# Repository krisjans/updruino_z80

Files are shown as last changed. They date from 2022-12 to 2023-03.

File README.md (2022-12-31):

# updruino_z80
Use Updruino FPGA boarad (iCE40-UP5K-SG48) as bridge between ZX Spectrum and Raspberry Pi

# warning!
This project uses iCE40-UP5K-SG48 in "CRAM" mode.

By default Updruino ships in "flash mode".

You must re-solder two 0Ohm resistors from Horizontal "Flash" positions to vertical "CRAM" positions.

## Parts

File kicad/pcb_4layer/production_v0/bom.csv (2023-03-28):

Designator | Footprint | Quantity | Value | LCSC Part #
C1, C10, C16, C18, C19, C2, C20, C23, C24, C25, C27, C28, C3, C4, C5, C6, C8, C9 | C_0805_2012Metric | 18 | 0.1uF
C11, C12, C13, C14, C15, C17, C29 | C_0805_2012Metric | 7 | 4.7uF
D1 | D_SOD-123 | 1 | B5819W SL | C8598
R1, R10, R11, R12, R13, R14, R15, R16, R17, R18, R19, R2, R9 | R_1206_3216Metric | 13 | 10K
R3, R4, R5, R6 | R_0805_2012Metric | 4 | 510
R7, R8 | R_0805_2012Metric | 2 | 240
U1, U3, U5, U6 | TSSOP-24_L7.8-W4.4-P0.65-LS6.4-BL | 4 | SN74LVCC4245APWR | C7035
U2 | SOP-28_L18.2-W8.5-P1.27-LS12.1-BL | 1 | LY62256SL-70LLI | C261868
U7, U8 | SOIC-14_L8.7-W3.9-P1.27-LS6.0-BL | 2 | 74HC125D | C5598

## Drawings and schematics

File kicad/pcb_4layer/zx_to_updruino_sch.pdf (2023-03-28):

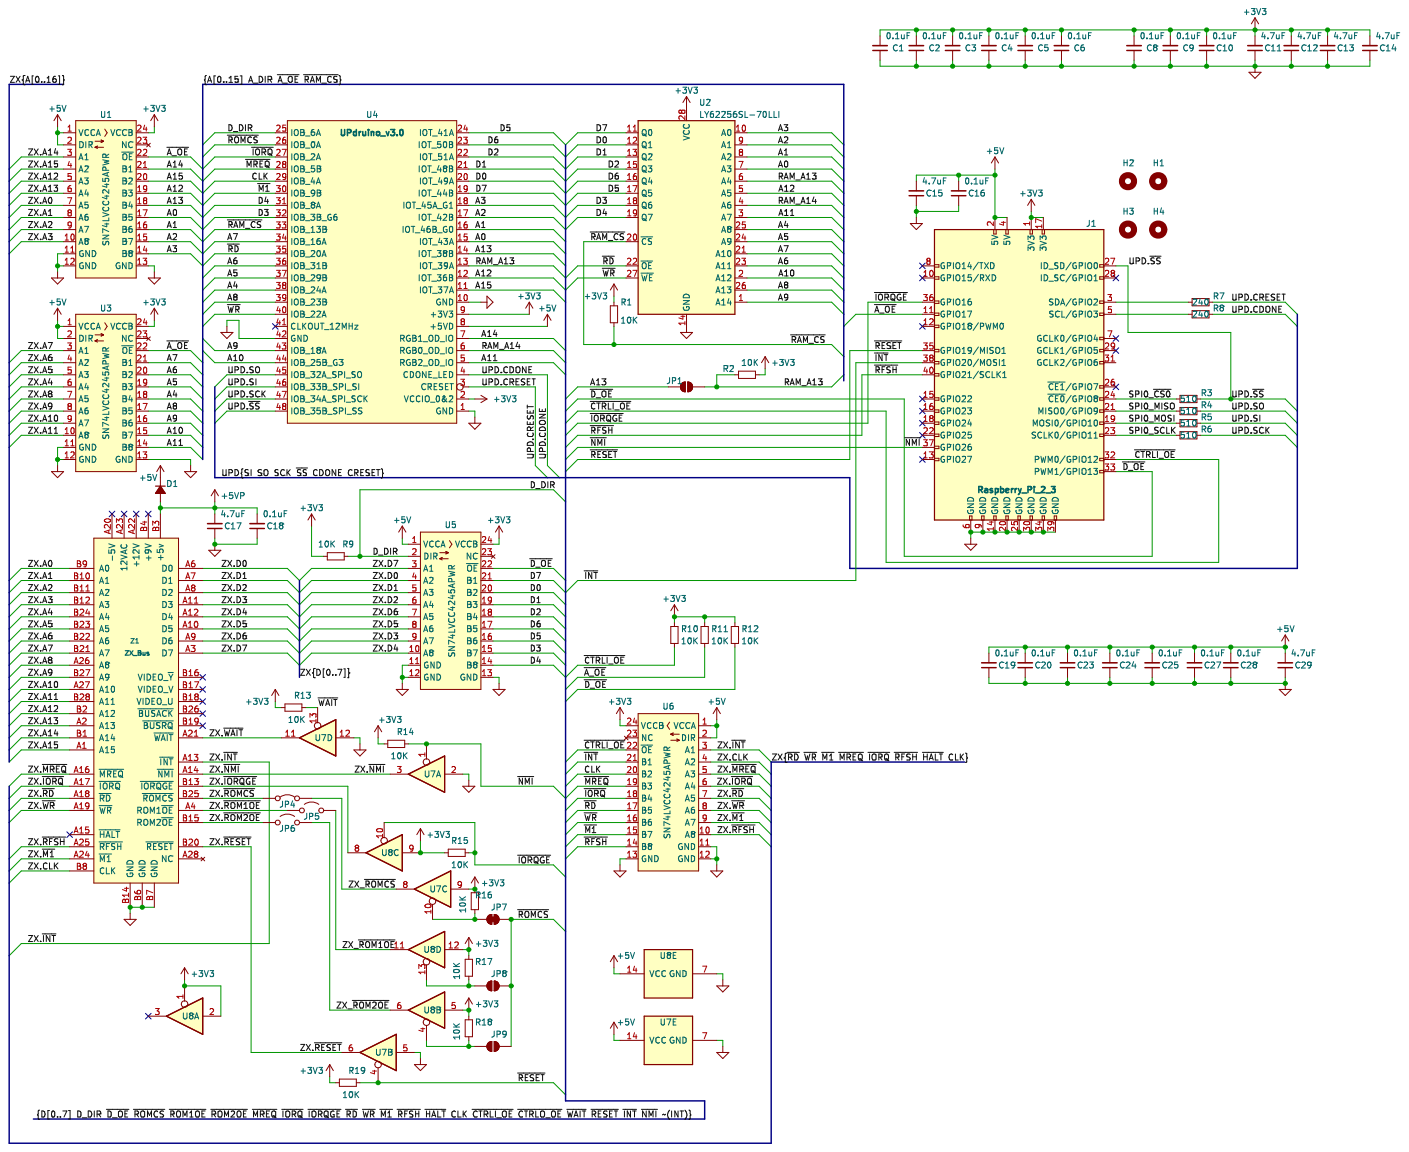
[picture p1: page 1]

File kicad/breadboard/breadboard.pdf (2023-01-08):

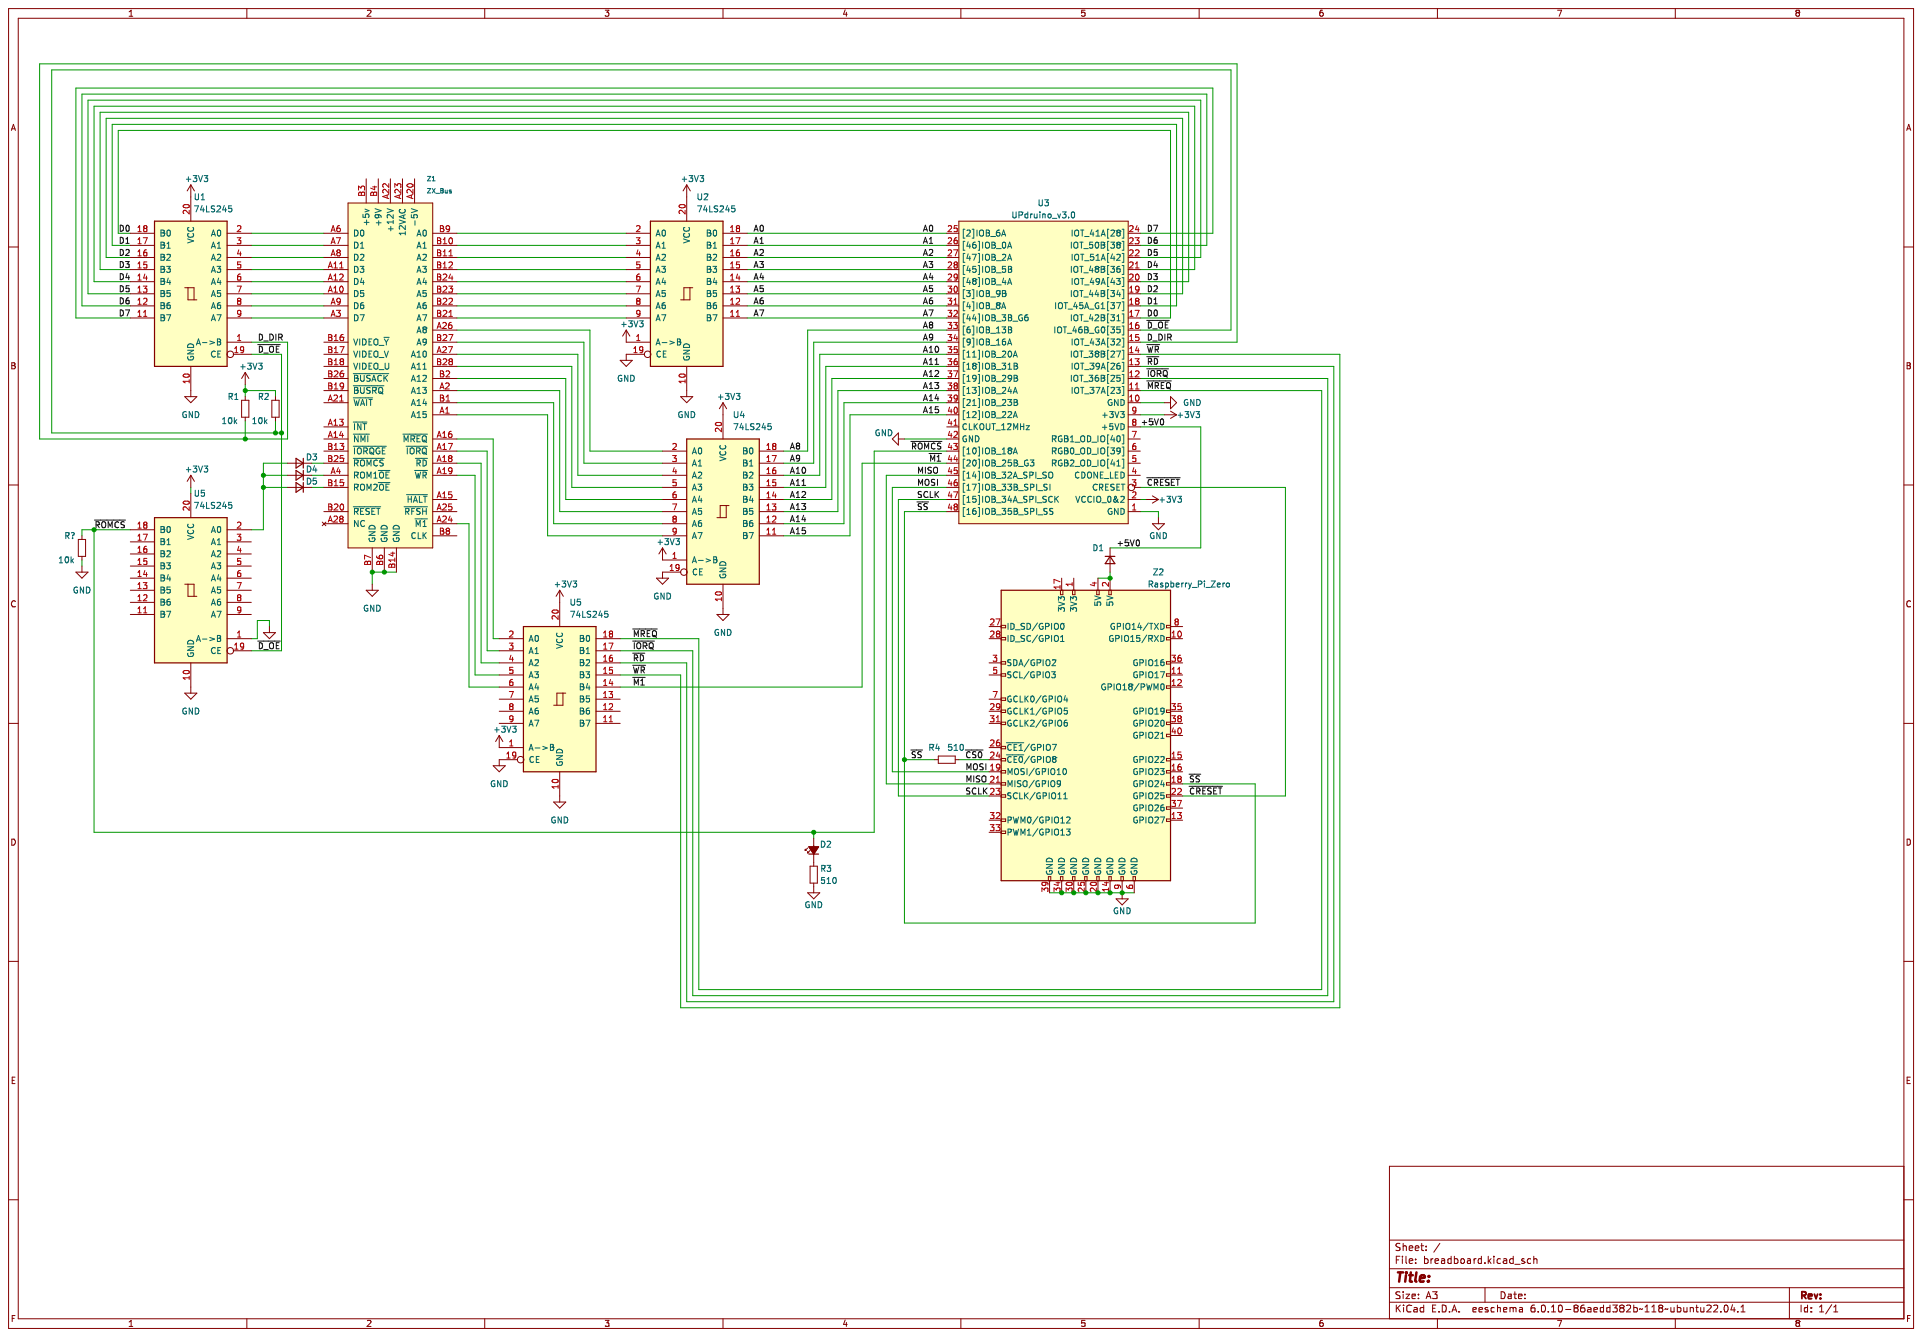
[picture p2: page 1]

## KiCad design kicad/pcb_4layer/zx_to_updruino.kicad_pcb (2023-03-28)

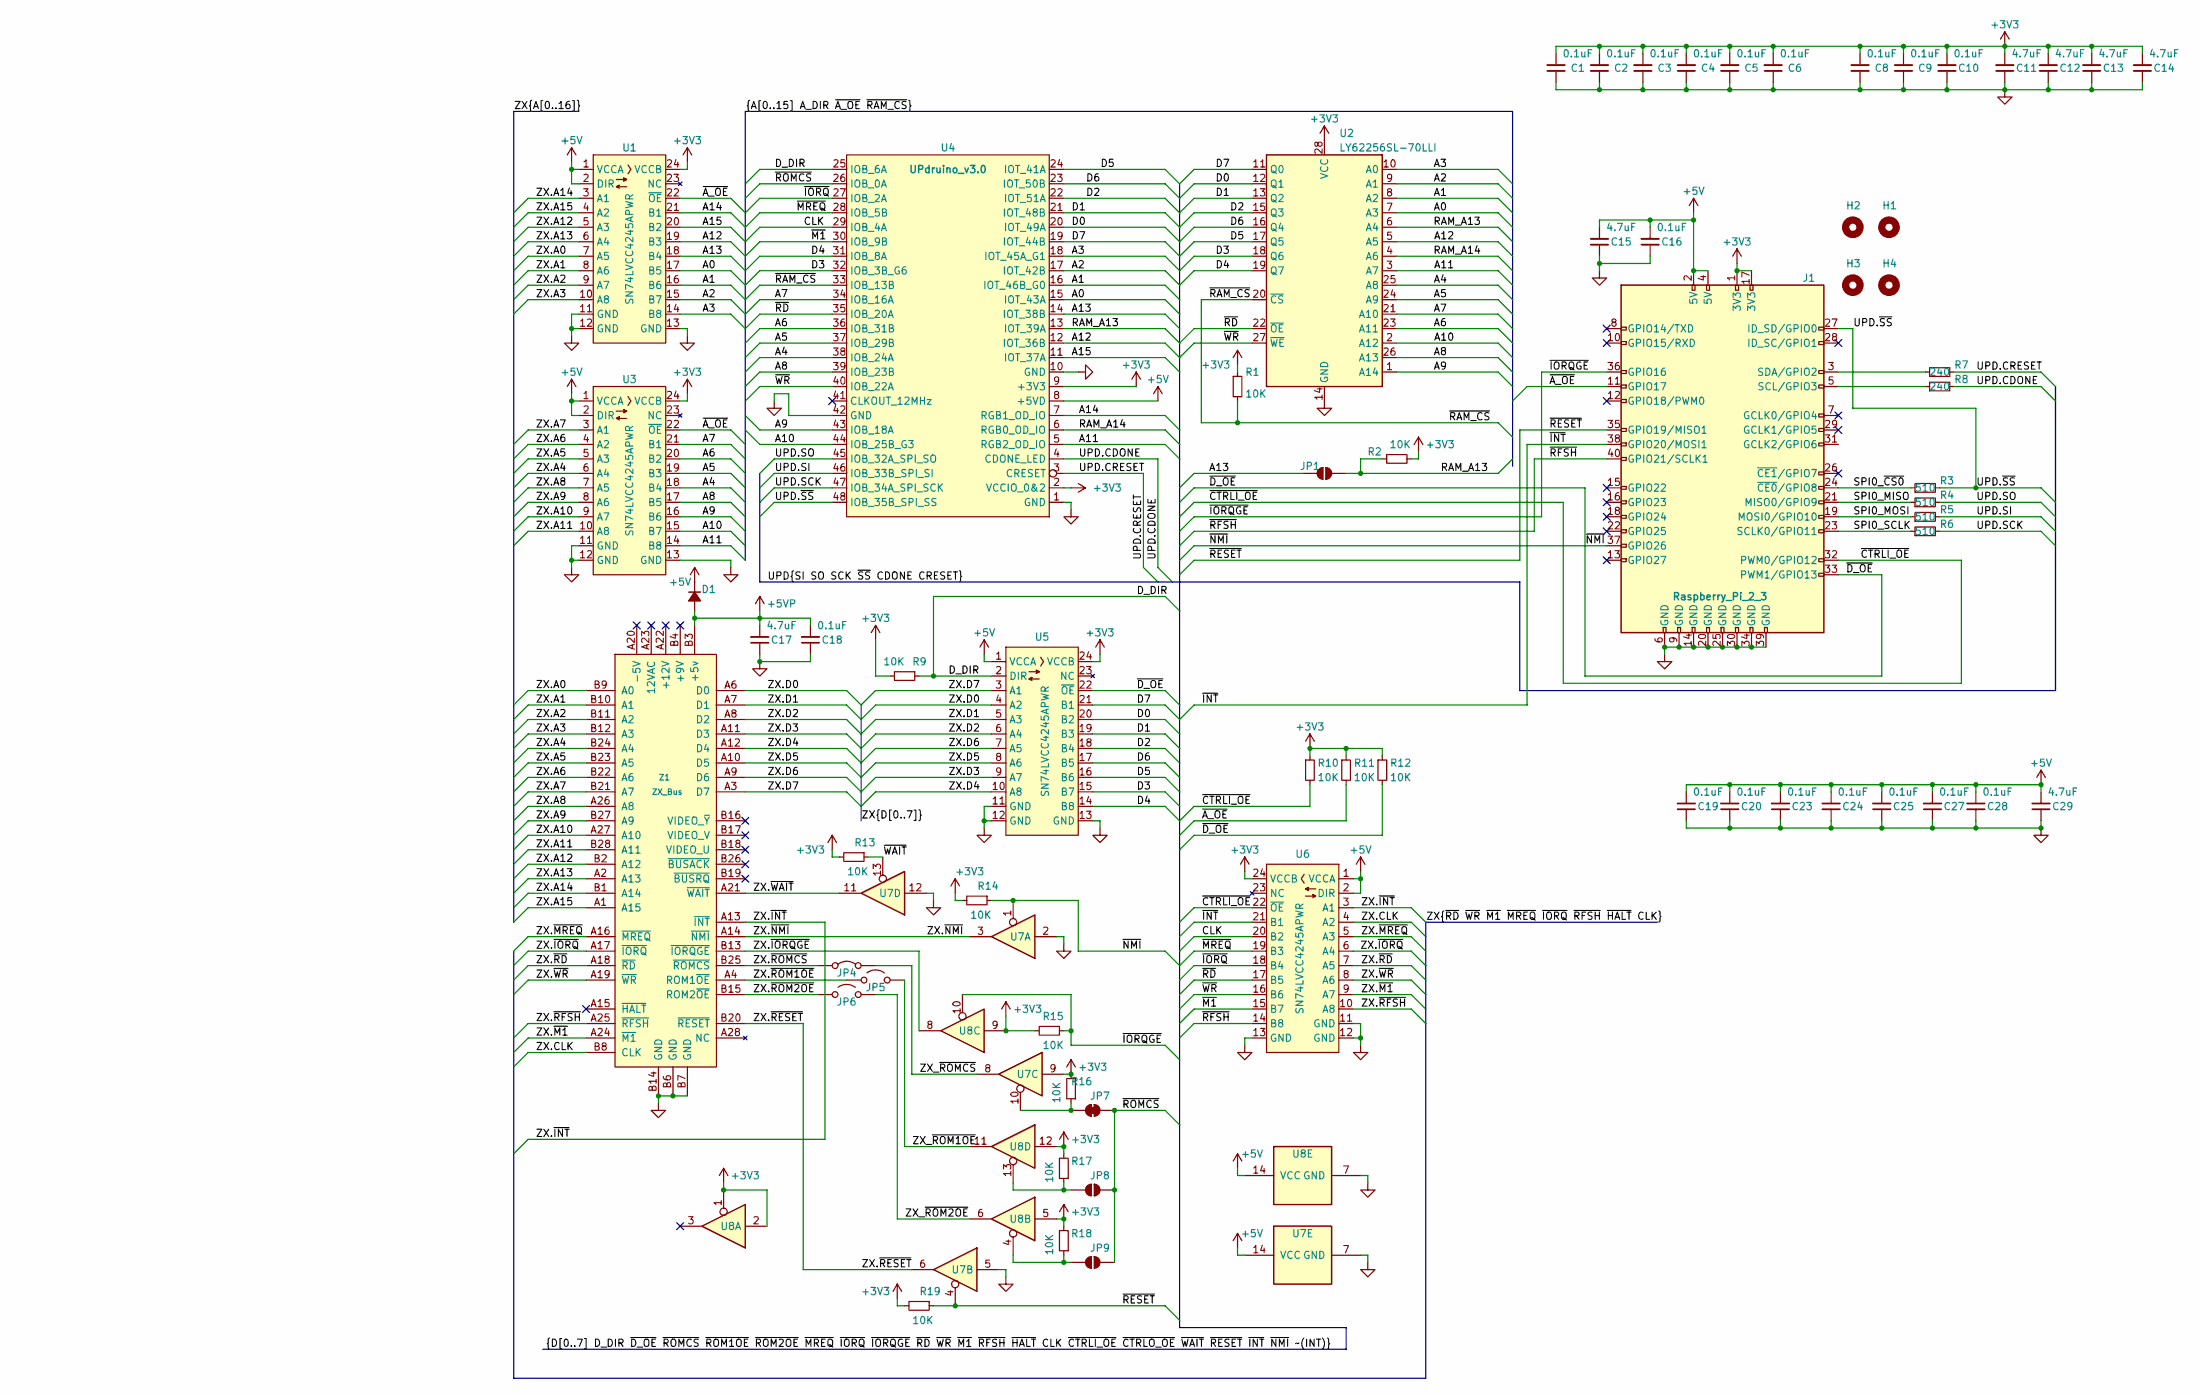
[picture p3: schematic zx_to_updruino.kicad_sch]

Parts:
C1, C2, C3, C4, C5, C6, C8, C9, C10, C16, C18, C19, C20, C23, C24, C25, C27, C28: 0.1uF; C_0805_2012Metric
C11, C12, C13, C14, C15, C17, C29: 4.7uF; C_0805_2012Metric
D1: B5819W SL; D_SOD-123; LCSC C8598
H1, H2, H3, H4: MountingHole
J1: Raspberry_Pi_2_3; PinSocket_2x20_P2.54mm_Vertical
JP1, JP8, JP9: SolderJumper_2_Bridged; SolderJumper-2_P1.3mm_Open_RoundedPad1.0x1.5mm
JP4, JP5, JP6: Jumper_2_Bridged; PinSocket_1x02_P2.54mm_Vertical
JP7: SolderJumper_2_Bridged; SolderJumper-2_P1.3mm_Bridged_RoundedPad1.0x1.5mm
R1, R2, R9, R10, R11, R12, R13, R14, R15, R16, R17, R18, R19: 10K; R_1206_3216Metric
R3, R4, R5, R6: 510; R_0805_2012Metric
R7, R8: 240; R_0805_2012Metric
U1, U3, U5, U6: SN74LVCC4245APWR; TSSOP-24_L7.8-W4.4-P0.65-LS6.4-BL; LCSC C7035
U2: LY62256SL-70LLI; SOP-28_L18.2-W8.5-P1.27-LS12.1-BL; LCSC C261868
U4: UPdruino_v3.0
U7, U8: 74HC125D; SOIC-14_L8.7-W3.9-P1.27-LS6.0-BL; LCSC C5598
Z1: ZX_Bus; ZX_Bus_Edge_Connector

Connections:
+3V3: C1.2, C2.2, C3.2, C4.2, C5.2, C6.2, C8.2, C9.2, C10.2, C11.2, C12.2, C13.2, C14.2, J1.1 (3V3), J1.17 (3V3), R1.1, R2.2, R9.2, R10.1, R11.1, R12.1, R13.2, R14.2, R15.2, R16.2, R17.2, R18.2, R19.2, U1.24 (VCCB), U2.28 (VCC), U3.24 (VCCB), U4.2 (VCCIO_0&2), U4.9 (+3V3), U5.24 (VCCB), U6.24 (VCCB), U7.9, U8.1, U8.2, U8.5, U8.9, U8.12
+5V: C15.2, C16.2, C19.2, C20.2, C23.2, C24.2, C25.2, C27.2, C28.2, C29.2, D1.1 (K), J1.2 (5V), J1.4 (5V), U1.1 (VCCA), U1.2 (DIR), U3.1 (VCCA), U3.2 (DIR), U4.8 (+5VD), U5.1 (VCCA), U6.1 (VCCA), U6.2 (DIR), U7.14 (VCC), U8.14 (VCC)
+5VP: C17.2, C18.2, D1.2 (A), Z1.B3 (+5v)
/A0: U1.17 (B5), U2.7 (A3), U4.15 (IOT_43A)
/A1: U1.16 (B6), U2.8 (A2), U4.16 (IOT_46B_G0)
/A2: U1.15 (B7), U2.9 (A1), U4.17 (IOT_42B)
/A3: U1.14 (B8), U2.10 (A0), U4.18 (IOT_45A_G1)
/A4: U2.25 (A8), U3.18 (B4), U4.38 (IOB_24A)
/A5: U2.24 (A9), U3.19 (B3), U4.37 (IOB_29B)
/A6: U2.23 (A11), U3.20 (B2), U4.36 (IOB_31B)
/A7: U2.21 (A10), U3.21 (B1), U4.34 (IOB_16A)
/A8: U2.26 (A13), U3.17 (B5), U4.39 (IOB_23B)
/A9: U2.1 (A14), U3.16 (B6), U4.43 (IOB_18A)
/A10: U2.2 (A12), U3.15 (B7), U4.44 (IOB_25B_G3)
/A11: U2.3 (A7), U3.14 (B8), U4.5 (RGB2_OD_IO)
/A12: U1.19 (B3), U2.5 (A5), U4.12 (IOT_36B)
/A13: JP1.1 (A), U1.18 (B4), U4.14 (IOT_38B)
/A14: U1.21 (B1), U4.7 (RGB1_OD_IO)
/A15: U1.20 (B2), U4.11 (IOT_37A)
/CLK: U4.29 (IOB_4A), U6.20 (B2)
/D0: U2.12 (Q1), U4.20 (IOT_49A), U5.20 (B2)
/D1: U2.13 (Q2), U4.21 (IOT_48B), U5.19 (B3)
/D2: U2.15 (Q3), U4.22 (IOT_51A), U5.18 (B4)
/D3: U2.18 (Q6), U4.32 (IOB_3B_G6), U5.15 (B7)
/D4: U2.19 (Q7), U4.31 (IOB_8A), U5.14 (B8)
/D5: U2.17 (Q5), U4.24 (IOT_41A), U5.16 (B6)
/D6: U2.16 (Q4), U4.23 (IOT_50B), U5.17 (B5)
/D7: U2.11 (Q0), U4.19 (IOT_44B), U5.21 (B1)
/D_DIR: R9.1, U4.25 (IOB_6A), U5.2 (DIR)
/RAM_A13: JP1.2 (B), R2.1, U2.6 (A4), U4.13 (IOT_39A)
/RAM_A14: U2.4 (A6), U4.6 (RGB0_OD_IO)
/SPI0_MISO: J1.21 (MISO0/GPIO9), R4.1
/SPI0_MOSI: J1.19 (MOSI0/GPIO10), R5.1
/SPI0_SCLK: J1.23 (SCLK0/GPIO11), R6.1
/SPI0_~CS0: J1.24 (~CE0/GPIO8), R3.1
/UPD.CDONE: R8.2, U4.4 (CDONE_LED)
/UPD.CRESET: R7.2, U4.3 (CRESET)
/UPD.SCK: R6.2, U4.47 (IOB_34A_SPI_SCK)
/UPD.SI: R5.2, U4.46 (IOB_33B_SPI_SI)
/UPD.SO: R4.2, U4.45 (IOB_32A_SPI_SO)
/UPD.~SS: J1.27 (ID_SD/GPIO0), R3.2, U4.48 (IOB_35B_SPI_SS)
/ZX.A0: U1.7 (A5), Z1.B9 (A0)
/ZX.A1: U1.8 (A6), Z1.B10 (A1)
/ZX.A2: U1.9 (A7), Z1.B11 (A2)
/ZX.A3: U1.10 (A8), Z1.B12 (A3)
/ZX.A4: U3.6 (A4), Z1.B24 (A4)
/ZX.A5: U3.5 (A3), Z1.B23 (A5)
/ZX.A6: U3.4 (A2), Z1.B22 (A6)
/ZX.A7: U3.3 (A1), Z1.B21 (A7)
/ZX.A8: U3.7 (A5), Z1.A26 (A8)
/ZX.A9: U3.8 (A6), Z1.B27 (A9)
/ZX.A10: U3.9 (A7), Z1.A27 (A10)
/ZX.A11: U3.10 (A8), Z1.B28 (A11)
/ZX.A12: U1.5 (A3), Z1.B2 (A12)
/ZX.A13: U1.6 (A4), Z1.A2 (A13)
/ZX.A14: U1.3 (A1), Z1.B1 (A14)
/ZX.A15: U1.4 (A2), Z1.A1 (A15)
/ZX.CLK: U6.4 (A2), Z1.B8 (CLK)
/ZX.D0: U5.4 (A2), Z1.A6 (D0)
/ZX.D1: U5.5 (A3), Z1.A7 (D1)
/ZX.D2: U5.6 (A4), Z1.A8 (D2)
/ZX.D3: U5.9 (A7), Z1.A11 (D3)
/ZX.D4: U5.10 (A8), Z1.A12 (D4)
/ZX.D5: U5.8 (A6), Z1.A10 (D5)
/ZX.D6: U5.7 (A5), Z1.A9 (D6)
/ZX.D7: U5.3 (A1), Z1.A3 (D7)
/ZX.~INT: U6.3 (A1), Z1.A13 (~INT)
/ZX.~IORQGE: U8.8, Z1.B13 (~IORQGE)
/ZX.~IORQ: U6.6 (A4), Z1.A17 (~IORQ)
/ZX.~M1: U6.9 (A7), Z1.A24 (~M1)
/ZX.~MREQ: U6.5 (A3), Z1.A16 (~MREQ)
/ZX.~NMI: U7.3, Z1.A14 (~NMI)
/ZX.~RD: U6.7 (A5), Z1.A18 (~RD)
/ZX.~RESET: U7.6, Z1.B20 (~RESET)
/ZX.~RFSH: U6.10 (A8), Z1.A25 (~RFSH)
/ZX.~ROM1OE: JP5.1 (A), Z1.A4 (ROM1~OE)
/ZX.~ROM2OE: JP6.1 (A), Z1.B15 (ROM2~OE)
/ZX.~ROMCS: JP4.1 (A), Z1.B25 (~ROMCS)
/ZX.~WAIT: U7.11, Z1.A21 (~WAIT)
/ZX.~WR: U6.8 (A6), Z1.A19 (~WR)
/ZX_~ROM1OE: JP5.2 (B), U8.11
/ZX_~ROM2OE: JP6.2 (B), U8.6
/ZX_~ROMCS: JP4.2 (B), U7.8
/~A_OE: J1.11 (GPIO17), R11.2, U1.22 (~OE), U3.22 (~OE)
/~CTRLI_OE: J1.32 (PWM0/GPIO12), R10.2, U6.22 (~OE)
/~INT: J1.38 (GPIO20/MOSI1), U6.21 (B1)
/~IORQGE: J1.36 (GPIO16), R15.1, U8.10
/~IORQ: U4.27 (IOB_2A), U6.18 (B4)
/~M1: U4.30 (IOB_9B), U6.15 (B7)
/~MREQ: U4.28 (IOB_5B), U6.19 (B3)
/~RAM_CS: R1.2, U2.20 (~CS), U4.33 (IOB_13B)
/~RD: U2.22 (~OE), U4.35 (IOB_20A), U6.17 (B5)
/~RESET: J1.35 (GPIO19/MISO1), R19.1, U7.4
/~RFSH: J1.40 (GPIO21/SCLK1), U6.14 (B8)
/~ROMCS: JP7.1 (A), JP8.2 (B), JP9.2 (B), U4.26 (IOB_0A)
/~WAIT: R13.1, U7.13
/~WR: U2.27 (~WE), U4.40 (IOB_22A), U6.16 (B6)
GND: C1.1, C2.1, C3.1, C4.1, C5.1, C6.1, C8.1, C9.1, C10.1, C11.1, C12.1, C13.1, C14.1, C15.1, C16.1, C17.1, C18.1, C19.1, C20.1, C23.1, C24.1, C25.1, C27.1, C28.1, C29.1, J1.6 (GND), J1.9 (GND), J1.14 (GND), J1.20 (GND), J1.25 (GND), J1.30 (GND), J1.34 (GND), J1.39 (GND), U1.11 (GND), U1.12 (GND), U1.13 (GND), U2.14 (GND), U3.11 (GND), U3.12 (GND), U3.13 (GND), U4.1 (GND), U4.10 (GND), U4.42 (GND), U5.11 (GND), U5.12 (GND), U5.13 (GND), U6.11 (GND), U6.12 (GND), U6.13 (GND), U7.2, U7.5, U7.7 (GND), U7.12, U8.7 (GND), Z1.B6 (GND), Z1.B7 (GND), Z1.B14 (GND)
unnamed: J1.3 (SDA/GPIO2), R7.1
unnamed: J1.5 (SCL/GPIO3), R8.1
unnamed: JP7.2 (B), R16.1, U7.10
unnamed: JP8.1 (A), R17.1, U8.13
unnamed: JP9.1 (A), R18.1, U8.4

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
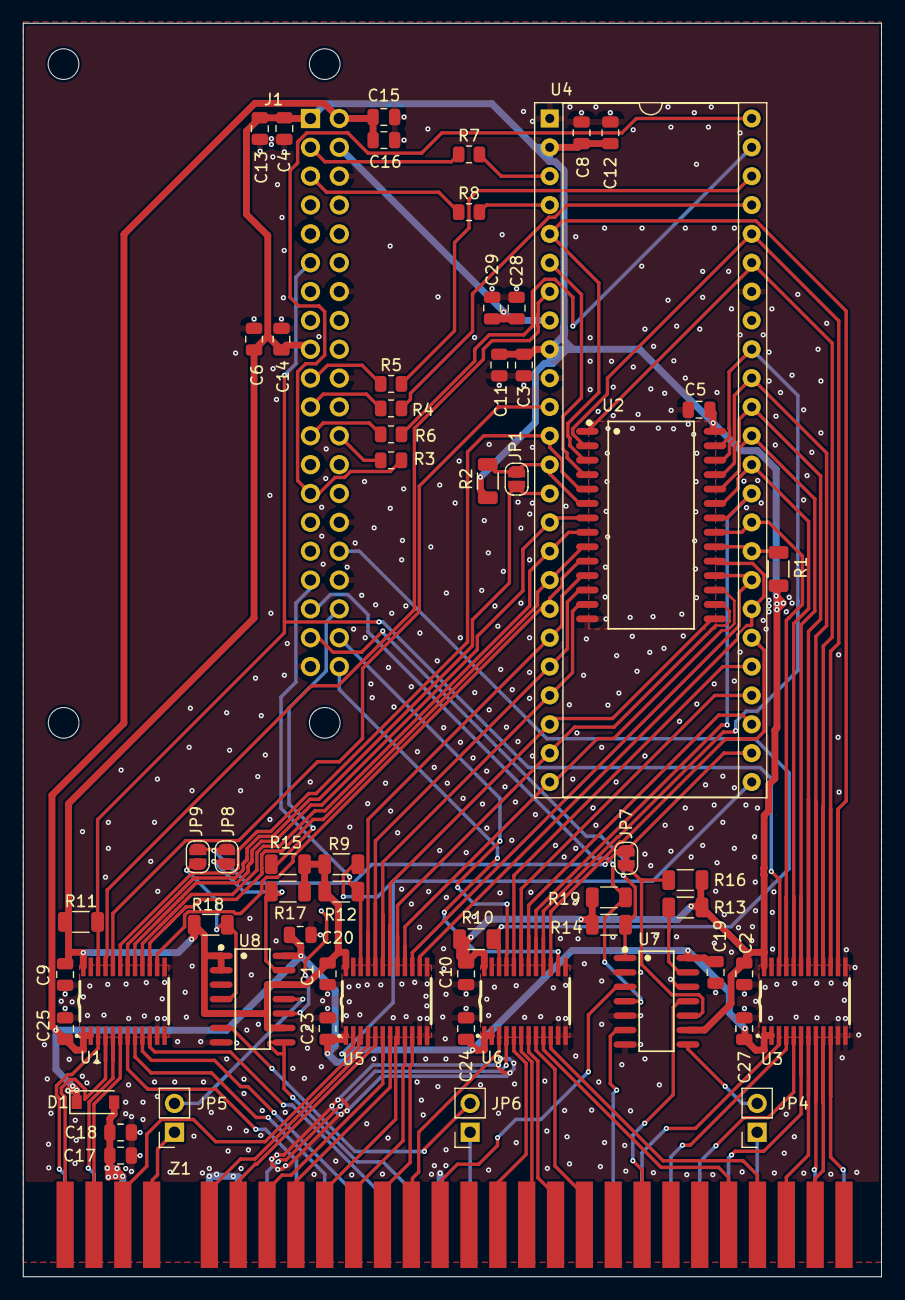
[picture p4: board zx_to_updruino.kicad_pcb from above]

Board: 4 copper layers, 75.6 x 110.4 mm, 66 parts (1 on the bottom side), 105 nets.

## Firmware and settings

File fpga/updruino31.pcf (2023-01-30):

set_io z80_a[0]  32
set_io z80_a[1]  35
set_io z80_a[2]  31
set_io z80_a[3]  37
set_io z80_a[4]  13
set_io z80_a[5]  19
set_io z80_a[6]  18
set_io z80_a[7]   9
set_io z80_a[8]  21
set_io z80_a[9]  10
set_io z80_a[10] 20
set_io z80_a[11] 41
set_io z80_a[12] 25
set_io z80_a[13] 27
set_io z80_a[14] 40
set_io z80_a[15] 23
set_io z80_d[0]  43
set_io z80_d[1]  36
set_io z80_d[2]  42
set_io z80_d[3]  44
set_io z80_d[4]   4
set_io z80_d[5]  28
set_io z80_d[6]  38
set_io z80_d[7]  34
#set_io z80_d_oe  Raspberry Pi GPIO-13
set_io z80_d_dir  2
set_io z80_wr    12
set_io z80_rd    11
set_io z80_iorq  47
set_io z80_mreq  45
set_io z80_m1     3
set_io z80_romcs 46
set_io z80_clk   48

set_io ram_a13   26
set_io ram_a14   39
set_io ram_cs     6

set_io spi_ss    16
set_io spi_sck   15
set_io spi_si    17
set_io spi_so    14

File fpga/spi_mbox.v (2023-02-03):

module spi_mbox (input [15:0] z80_a,
                 input spi_sck,
                 input spi_ss,
                 input spi_si,
                 output spi_so,
                 input clk,
                 output [8*8-1:0] spi_to_z80_flat,
                 input [8*8-1:0] z80_to_spi_flat);

    reg [7:0] spi_to_z80[7:0];
    wire [7:0] z80_to_spi[7:0];

    assign spi_to_z80_flat = {spi_to_z80[7], spi_to_z80[6], spi_to_z80[5], spi_to_z80[4],
                              spi_to_z80[3], spi_to_z80[2], spi_to_z80[1], spi_to_z80[0]};
    assign {z80_to_spi[7], z80_to_spi[6], z80_to_spi[5], z80_to_spi[4],
            z80_to_spi[3], z80_to_spi[2], z80_to_spi[1], z80_to_spi[0]} = z80_to_spi_flat;

// ------------------------------------------------------------------------
// SPI stuff --------------------------------------------------------------
// ------------------------------------------------------------------------

    initial begin
        spi_to_z80[0] <= 8'd111;
        spi_to_z80[1] <= 8'd122;
        spi_to_z80[2] <= 8'd133;
        spi_to_z80[3] <= 8'd144;
        spi_to_z80[4] <= 8'd155;
        spi_to_z80[5] <= 8'd166;
        spi_to_z80[6] <= 8'd177;
        spi_to_z80[7] <= 8'd188;
    end

    localparam SPICR0  = 'h08,
               SPICR1  = 'h09,
               SPICR2  = 'h0a,
               SPIBR   = 'h0b,
               SPISR   = 'h0c,
               SPISR_TIP  = 7,
               SPISR_BUSY = 6,
               SPISR_TRDY = 4,
               SPISR_RRDY = 3,
               SPITXDR = 'h0d,
               SPIRXDR = 'h0e,
               SPICSR  = 'h0f;

    localparam SB_WR = 1'b1, SB_RD = 1'b0;

    localparam SM_SET_SPICR0 = 0,
               SM_SET_SPICR1 = SM_SET_SPICR0 + 1,
               SM_SET_SPICR2 = SM_SET_SPICR1 + 1,
               SM_SET_SPIBR  = SM_SET_SPICR2 + 1,
               SM_SET_SPICSR = SM_SET_SPIBR + 1,
               SM_RD_STS = SM_SET_SPICSR + 1,
               SM_TRANSMIT = SM_RD_STS + 1,
               SM_RECEIVE = SM_TRANSMIT + 1;
    reg [7:0] spi_sm_state;

    reg sbrw;
    reg [7:0] sbadr;
    reg [7:0] sbdati;
    wire [7:0] sbdato;
    reg sbstb;
    wire sback;

    SB_SPI SB_SPI_inst(
        .SBCLKI(clk),
        .SBRWI(sbrw),
        .SBSTBI(sbstb),
        .SBADRI0(sbadr[0]),
        .SBADRI1(sbadr[1]),
        .SBADRI2(sbadr[2]),
        .SBADRI3(sbadr[3]),
        .SBADRI4(sbadr[4]),
        .SBADRI5(sbadr[5]),
        .SBADRI6(sbadr[6]),
        .SBADRI7(sbadr[7]),
        .SBDATI0(sbdati[0]),
        .SBDATI1(sbdati[1]),
        .SBDATI2(sbdati[2]),
        .SBDATI3(sbdati[3]),
        .SBDATI4(sbdati[4]),
        .SBDATI5(sbdati[5]),
        .SBDATI6(sbdati[6]),
        .SBDATI7(sbdati[7]),
        .SBDATO0(sbdato[0]),
        .SBDATO1(sbdato[1]),
        .SBDATO2(sbdato[2]),
        .SBDATO3(sbdato[3]),
        .SBDATO4(sbdato[4]),
        .SBDATO5(sbdato[5]),
        .SBDATO6(sbdato[6]),
        .SBDATO7(sbdato[7]),
        .SBACKO(sback),
        .SO(spi_so),
        .SI(spi_si),
        .SCKI(spi_sck),
      .SCSNI(spi_ss)
    );
    defparam SB_SPI_inst.BUS_ADDR74 = "0b0000"; // should not be necessary, but "apio build" fails without it

    reg [2:0] spi_tx_index;
    reg [2:0] spi_rx_index;

    reg spi_old_ss;

    initial begin
        sbstb = 0;
        sbrw = 0;
        sbadr = 0;
        sbdati = 0;
        spi_tx_index = 0;
        spi_rx_index = 0;
        spi_old_ss = 0;
        spi_sm_state = SM_SET_SPICR0;
    end

    always @(posedge clk)
    begin
        if (sbstb == 1'b0) begin
            case (spi_sm_state)
            SM_SET_SPICR0 : begin
                sbadr <= SPICR0;
                sbdati <= 8'h00;
                sbrw <= SB_WR;
            end
            SM_SET_SPICR1 : begin
                sbadr <= SPICR1;
                sbdati <= 8'h80;
                sbrw <= SB_WR;
            end
            SM_SET_SPICR2 : begin
                sbadr <= SPICR2;
                sbdati <= 8'h00;
                sbrw <= SB_WR;
            end
            SM_SET_SPIBR : begin
                sbadr <= SPIBR;
                sbdati <= 8'h00;
                sbrw <= SB_WR;
            end
            SM_SET_SPICSR : begin
                sbadr <= SPICSR;
                sbdati <= 8'h00;
                sbrw <= SB_WR;
            end
            SM_RD_STS: begin
                sbadr <= SPISR;
                sbrw <= SB_RD;
            end
            SM_TRANSMIT: begin
                sbadr <= SPITXDR;
                sbdati <= z80_to_spi[spi_tx_index];
                spi_tx_index <= spi_tx_index + 1;
                sbrw <= SB_WR;
            end
            SM_RECEIVE: begin
                sbadr <= SPIRXDR;
                sbrw <= SB_RD;
            end
            endcase
            sbstb <= 1;

        end else begin
            if (sback == 1'b1) begin
                case (spi_sm_state)
                SM_SET_SPICR0,
                SM_SET_SPICR1,
                SM_SET_SPICR2,
                SM_SET_SPIBR,
                SM_SET_SPICSR : begin
                    spi_sm_state <= spi_sm_state + 1;
                end
                SM_RD_STS: begin
                    if (spi_ss == 0) begin
                        if (spi_old_ss == 1) begin
                            spi_old_ss <= 0;
                            spi_rx_index <= 0;
                            spi_tx_index <= 0;
                            spi_sm_state <= SM_TRANSMIT;
                        end
                        if (sbdato[SPISR_TRDY] == 1) begin
                            spi_sm_state <= SM_TRANSMIT;
                        end else if (sbdato[SPISR_RRDY] == 1) begin
                            spi_sm_state <= SM_RECEIVE;
                        end
                    end else begin
                        if (spi_old_ss == 0) begin
                            spi_old_ss <= 1;
                            spi_tx_index <= 0;
                            spi_sm_state <= SM_TRANSMIT;
                        end
                    end
                end
                SM_TRANSMIT: begin
                    spi_sm_state <= SM_RD_STS;
                end
                SM_RECEIVE: begin
                    spi_to_z80[spi_rx_index] <= sbdato;
                    spi_rx_index <= spi_rx_index + 1;
                    spi_sm_state <= SM_RD_STS;
                end
                endcase
                sbstb <= 0;
            end
        end
    end

endmodule

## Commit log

2022-12-28 Switch on test_led if write to Z80 IO port 12345 happened; Switch off test_led if read from Z80 IO port 12345 happened;
2022-12-31 Add SPI-subordinate support; 8 bytes from Z80 IO ports to/from SPI;
2022-12-31 Add PC test tool to test SPI using FTDI chip;
2022-12-31 Fix timing bug in FPGA: Z80 IO port read/write was clashing;
    [z80_bus.v]
2022-12-31 Add KiCad schematics;
    [breadboard.kicad_sch]
2023-01-06 Python test programm for Raspberry PI to send/receive using SPI;
2023-01-06 Python test programm for Raspberry PI to upload FPGA firmware in CRAM
2023-01-08 Enable Battery Charge Detection (USB charging cable) in FTDI chip on UPduino board;
    This is needed to allow normal SPI operation when not using UPduino FTDI USB;
2023-01-08 schematics: update breadboard: add Raspberry PI Zero and Spectrum ROMCS signal;
    [breadboard.kicad_sch]
2023-01-08 testing: SPI over FTDI: set MSB first for SPI transactions;
2023-01-08 FPGA: FTDI: To program and use SPI need both - BCD and "self-powered";
2023-01-08 FPGA: implement 16k shadow-ROM using 15k block-RAM and 1K distributed-RAM;
    Active shadow-ROM using ZX Spectrum basic command 'OUT 12345,85' followed by reset;
    [updruino31.pcf, z80_bus.v]
2023-01-11 Makefile: fpga: move building to "build" target; Print device utilisation summary at the end;
2023-01-13 fpga: add meta-stability filters;
2023-01-30 Switch from breadboard to PCB;
2023-01-30 Switch to PCB: fix zx spectrum ROM disable signal polarity;
    [z80_bus.v]
2023-02-03 Move all SPI logic to separate module;
2023-02-04 FPGA: ftdi: test tool: print both hex and decimal values;
2023-03-28 kicad: PCB v0: Add 4 layer PCB schematics, pcb and production gerber files;
    [bom.csv, designators.csv, positions.csv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]
2023-03-28 kicad: add v0 schematic as pdf file;
